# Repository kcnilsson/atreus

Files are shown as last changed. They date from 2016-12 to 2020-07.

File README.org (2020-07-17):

* Atreus Keyboard

This repository is [[https://gitlab.com/technomancy/atreus][moved to GitLab]].

The Atreus is a mechanical keyboard designed primarily to match the
shape of human hands and to be as portable as possible. The case
measures 26x12cm and lacks even a number row, relying heavily upon the
=fn= key. There is a circuit board for this design, but it's also
possible to [[http://wiki.geekhack.org/index.php?title=Hard-Wiring_How-To][manually wire the matrix]].

I've seen a number of existing DIY 40% keyboard designs, but most of
them stagger the rows, which I find very annoying now that I've gotten
used to the columnar layout of the [[https://geekhack.org/index.php?topic=22780.0][Ergodox]]. In addition, many of the
designs I've seen waste a lot of room on the space bar, failing to
take into account the fact that the thumb is the strongest and most
versatile of the fingers. This design avoids both these problems while
taking a more couch-friendly single-piece approach.



See [[./changelog.md][the changelog]] for the various revisions made to the design since
its initial release.

** Kits

You can buy [[http://atreus.technomancy.us][Atreus kits]] that have all the parts you need along with
detailed assembly instructions from http://atreus.technomancy.us. If
you'd rather round up all the parts yourself, that's possible too
since the design is completely open source; see the bill of materials
below.

** Layout

Only a handful of punctuation marks (and no digits) are available
unshifted, and all the modifiers are on the bottom row:

 :    q     w     e     r     t       ||       y     u     i     o    p
 :    a     s     d     f     g       ||       h     j     k     l    ;
 :    z     x     c     v     b       ||       n     m     ,     .    /
 :   esc   tab  super shift bksp ctrl || alt space  fn     -     '  enter

The numbers and most of the punctuation are on the fn layer with a
numpad-style arrangement under the right hand:

 :    !    @     up     {    }        ||     pgup    7     8     9    *
 :    #  left   down  right  $        ||     pgdn    4     5     6    +
 :    [    ]      (     )    &        ||       `     1     2     3    \
 :   L2  insert super shift bksp ctrl || alt space   fn    .     0    =

The =L2= key switches it to the function layer, and tapping =L0= here
brings it back to the first layer.

 :  insert home    ↑    end  pgup     ||       ↑     F7    F8    F9   F10
 :    del   ←      ↓     →   pgdn     ||       ↓     F4    F5    F6   F11
 :                           reset    ||             F1    F2    F3   F12
 :              super shift bksp ctrl || alt space   L0             

The [[https://atreus.technomancy.us/download][firmware]] includes a number of other options, including
colemak and dvorak. [[https://atreus.technomancy.us/qmk][Customizing your layout]] is easy to do with the QMK configurator interface.

** Parts

*** Switches

This layout has five modifiers and 37 non-modifiers.

I strongly prefer the feel and sound of tactile [[https://deskthority.net/wiki/Matias_switch#Click][Matias Clicky]]
switches for typing. However, I like having [[https://deskthority.net/wiki/Matias_switch#Linear][Matias Linear
switches]] switches on the modifier keys (ctrl, alt, super, shift, and
fn) because the tactile effect has no benefit for keys that are held
down, and giving a different response helps you learn the layout more
quickly.

For users that need to operate in sound-sensitive environments like
open offices or libraries,
[[http://deskthority.net/wiki/Matias_switch#Quiet_click][Matias Quiet
Click]] switches are a popular choice since they still offer tactility
without the noise. Other users prefer switches in the
[[http://deskthority.net/wiki/Cherry_MX][Cherry MX]] family, which use
different keycaps and switch plates but still work fine.

*** Diodes

In order to avoid ghosting, each switch needs a diode. The [[https://www.radioshack.com/product/index.jsp?productId=2062587][1N4148]] is a
readily-available choice, but nearly any signal diode would work.

*** Microcontroller

The circuit board design uses a [[http://www.pololu.com/product/3101][Pololu A-star micro]]. Hand-wired boards
can also use a [[http://arduino.cc/en/Main/ArduinoBoardMicro][Arduino Pro Micro]].

Be sure to get a microcontroller without headers so it will fit in
between the bottom layer and the plate. USB micro is preferred over
USB mini for this reason as well.

*** Keycaps

Caps for Matias switches are included in the official kits. Sculpted
caps are also available [[http://matias.ca/order/#keycaps][from Matias]] or by harvesting from old Alps
keyboards. It's recommended that you use unlabeled keys, because due
to the different sizes and orientations of certain keys (backspace,
shift, enter, etc) many of the labels will be incorrect if present.

Cherry switches have more options. This
[[http://pimpmykeyboard.com/dsa-pbt-abs-blank-keycap-sets/][DSA-shaped base set]] (spherical indentations on the key, same profile for each
row) from Signature Plastics has 52 1x keys plus a few extras we won't
use. There are two "deep dish" keys in that set which you can place
under your index fingers on the home row to help guide your hands to
the right spot without looking. However, you only get a single 1.5x
keycap, and the middle two thumb keys both use them, so you might want
to pick up an extra.

** Circuit Board

The =atreus.rkt= program calculates switch and diode positions based
on row/column counts, spacing, and rotation factors, and emits a
=atreus.kicad_pcb= file. The board outline and traces are done by hand
and are stored in the =header.rktd= and =traces.rktd= files
respectively. The =atreus.kicad_pcb= file can be imported into [[http://kicad-pcb.org][Kicad]]
which can export Gerber files suitable for fabrication. A copy of the
Kicad PCB file is included in the repository if you don't want to
recompile it using Racket. Recompiling is only required if you want to
make changes to the procedurally-generated portions of the board.

Unfortunately most PCB fabricators require a minimum order of 10 or
so, making this impractical for one-offs. The PCB is not required, so
for one-off boards it's usually more sensible to stick with a [[http://atreus.technomancy.us/assembly-hand-wired.pdf][hand-wired build]] instead.

** Case

Layered laser-cut wood or acrylic. The [[http://geekhack.org/index.php?topic%3D54759.msg1304117#msg1304117][mark II case]] (EPS files in the
=case/= directory) features 8 screw holes and a kind of "stair step"
design around the top and bottom of the key clusters; mark I has
straight lines.

The files =alps-top-plate-3mm.eps=, =alps-switch-plate-3mm.eps=, and
=bottom-plate-3mm.eps= are to be cut in 3mm acrylic or wood. The
=spacer.eps= file can be cut on something thicker; between 4.5mm and
6mm is recommended. Alternatively you can cut it in 3mm twice. The
spacer needs to be at least as thick as the connector of the USB cable
you're using. If you are using Cherry switches, you should use
=cherry-3mm.eps= for the top, switch, and bottom plates instead, but
the spacer is the same.

There is also a programmatically-implemented version of the case
written in OpenSCAD; it is more flexible (you can tweak the number of
rows/cols, etc and recompile) but it doesn't match the canonical case
exactly; in particular the screw holes are placed differently.

The original case (=case-mk-i.svg=) design is also included; it is
slightly less wide and has a minor asymmetry with the screws on the
bottom side.

On a 100W Epilog laser, the 3mm layers cut in about a minute and a
half. I did a run with 6mm acrylic of the other layers which took
nearly 6 minutes.

Wood cases should be finished with sandpaper and lacquer, shellac, or polyurethane.

** Firmware

The [[https://qmk.fm][QMK firmware]] is
recommended. [[https://atreus.technomancy.us/download][Standard
layouts]] are available precompiled, or you can
[[https://atreus.technomancy.us/qmk][design your own]] in the
configurator.

There is also the older
[[https://github.com/technomancy/atreus-firmware][atreus-firmware]]
custom codebase which works but has fewer features. It is recommended
mostly for learning purposes since the code is much simpler and easier
to understand than QMK. Previously TMK was the recommended choice for
firmware, but QMK has much better documentation and ease of use and is
now recommended.

** Bill of Materials

If you don't want to get [[https://atreus.technomancy.us][the kit]] you can source parts yourself. (You
can also order a partial kit if you want to customize some of the
parts.) Using Cherry switches is cheapest unless you can find cheap
Alps-mount keycaps:

- 50 Matias or Cherry switches from mechanicalkeyboards.com
- 50 diodes from radio shack, ebay, or whatever
- 40 1x, 2 1.5x Keycaps from signatureplastics.com OR full keycap set from matias.ca
- A-star micro from pololu.com
- Case materials from various sources
- Case laser cutting: 7.5 minutes on a 100W Epilog laser; varies by source
- USB micro cable, get anywhere

Recommended but optional:

- 5 linear Matias or Cherry switches

The base keycap set from Signature Plastics only has one 1.5x key,
which is used for the inner thumb keys. You can use a 1x key for one
of them, but it looks kind of tacky, so I recommend getting a second
1.5x keycap separately.

*** Other Tools

You'll need a soldering iron, solder, and a wire cutter. A multimeter
can come in handy for testing the connections but is optional. You'll
also need eight M3 machine screws with nuts; the length of the screws
depends on the thickness of the acrylic you use. You can add rubber
feet to the bottom to prevent the board from sliding around when
placed on a desk. You'll also need sandpaper and lacquer for the
wooden case.

If you are building a hand-wired board you will also need a glue gun,
hookup wire, and wire strippers.

** Assembly

See the [[https://atreus.technomancy.us/assembly.pdf][assembly instructions]] PDF.

Hand-wired boards will want the [[https://atreus.technomancy.us/assembly-hand-wired.pdf][previous edition of the assembly instructions]].

The LaTeX source to the assembly instructions is in the =assembly= directory.

** Inspiration

These fine projects all provided inspiration for various aspects of
the Atreus, as well as the folks on the =#geekhack= freenode channel.

- [[https://geekhack.org/index.php?topic=22780.0][Ergodox]]
- [[http://deskthority.net/workshop-f7/onehand-20-keyboard-t6617.html][OneHand]]
- [[http://blog.fsck.com/2013/12/better-and-better-keyboards.html][keyboard.io]]
- [[http://geekhack.org/index.php?topic=48718][ErgoT]]

** Builds

If you've built an Atreus, please add your name to [[https://github.com/technomancy/atreus/wiki/BuildLogs][the build logs wiki]].

There's also a [[https://atreus.technomancy.us/list][mailing list]] for people who have built or ordered an
Atreus or are interested in doing so.

** Orestes

An [[https://www.flickr.com/photos/technomancy/14654421878][experimental build]] uses the [[http://pjrc.com/store/teensy31.html][Teensy 3]] microcontroller and
ARM [[https://github.com/technomancy/orestes/tree/teensy3][Forth-based]] firmware, but this is not really suitable for general-purpose use; it's more of a curiosity.

** License

Copyright © 2014-2018 Phil Hagelberg and contributors

Released under the [[https://www.gnu.org/licenses/gpl.html][GNU GPL version 3]]

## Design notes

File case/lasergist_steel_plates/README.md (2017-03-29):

Stainless Steel plates using Lasergist
======================================

The Atreus is a great portable ergonomic keyboard. For those who prefer a metal case, the following instructions show you how to build a floating-keys stainless steel Atreus using a switch plate and a bottom plate.

Photos: http://imgur.com/gallery/ZaZHV

Stainless Steel Atreus

The illustrator files are ready to be submitted as-is to Lasergist to make stainless steel plates (Cherry MX version)

Choose the following settings:
* Material: **AISI 304 - Shiny**
* Thickness: **1.5 mm**
* **Sandblasting**

Upload the two files:
* **switch-plate-only.ai**
  * Overall dimensions: height: 116mm width: 257mm
  * Path lengths: 3369mm
* **base-plate-only.ai**
  * Overall dimensions: height: 116mm width: 257mm
  * Path lengths: 749mm

The order comes out to about $95 USD, including shipping.
  
Additionally, you'll need the following hardware:
* 8x 14mm long M3 screws, low profile head https://www.mcmaster.com/#93070A071
* 8x 8mm long M3 hex nuts https://www.mcmaster.com/#94868A603
* 8x M3 small hex nuts https://www.mcmaster.com/#98676A100

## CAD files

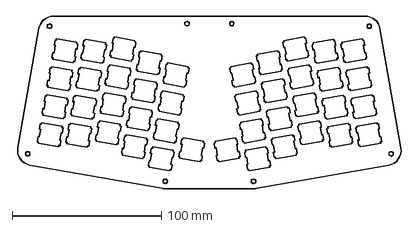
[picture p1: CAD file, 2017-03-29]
case/lasergist_steel_plates/switch-plate-only.dxf
258.3 x 115.8 mm

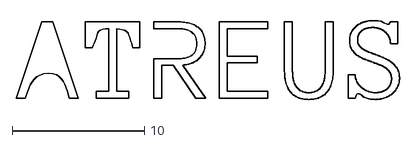
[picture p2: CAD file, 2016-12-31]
case/openscad/logo.dxf
28.9 x 5.96

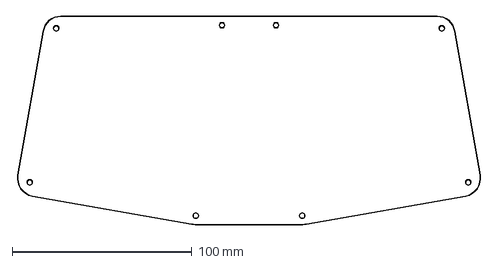
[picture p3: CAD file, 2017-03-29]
case/lasergist_steel_plates/base-plate-only.dxf
258.8 x 115.8 mm

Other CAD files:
case/openscad/atreus_case.scad

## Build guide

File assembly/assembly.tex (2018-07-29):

\documentclass[landscape,twocolumn]{article}
\title{Atreus Keyboard Assembly}
\date{ }
\usepackage{pdflscape}
\usepackage{graphicx}
\usepackage[landscape,twocolumn]{geometry}
\usepackage{wrapfig}
\newgeometry{margin=2cm}
\begin{document}
\setlength{\columnsep}{1.4cm}
\setlength{\parindent}{0cm}
\maketitle
\section{Prerequisites}

Before starting, make sure your kit has all its parts:

\begin{itemize}
\item Case: top plate, switch plate, spacer pieces, bottom plate
\item Sandpaper: 100-220 grit and 1000-2000 grit waterproof
\item Key switches: 42 tactile or clicky, 5 red optional
\item Printed circuit board (PCB)
\item A-Star Micro controller\footnote{The controller and diodes will be
  attached to the PCB already in presoldered boards.}
\item Diodes\textsuperscript{1}: 42
\item USB micro cable
\item Key caps: 40 normal, 2 long
\item Screws and nuts: 8 each, 16mm M3 size
\item Rubber feet
\end{itemize}

You'll also need to have these on hand:

\begin{itemize}
\item Can of spray lacquer, shellac, or polyurethane (for wood cases)
\item Newspaper or other material to spray on (for wood cases)
\item Soldering iron and solder (lead-free not recommended)
\item Wire cutters (not needed for presoldered kits)
\item Eye protection for soldering
\end{itemize}

\vspace{1em}

The latest version of this document can always be found
online.\footnote{https://atreus.technomancy.us/assembly.pdf} If you are
hand-wiring a board without a PCB, see the older assembly
guide.\footnote{https://atreus.technomancy.us/assembly-hand-wired.pdf}
The photos in this guide depict Matias switches (with rectangular
switch stems), but you can use Cherry MX switches (with stems shaped
like a +) as well.

\section{Sanding}

Acrylic cases can skip down to the ``Diodes'' step below. Otherwise
start by sanding with your rougher sandpaper. The top side of the top
plate and the bottom side of the bottom plate are the only surfaces
that are exposed to the touch once the keyboard is fully assembled, so
these are the ones you'll need to sand.

\vspace{1em}
\begin{center}
  
\end{center}
\vspace{1em}

You may want to hold two pieces together while sanding for strength or
placing it on a flat surface you don't mind scruffing up; too much
pressure on a single plate could damage it. Be sure to get all the
wood dust off the pieces before you go on. A clean tack cloth or other
fine cloth works well.

\vspace{1em}

Some people don't like the look of the exposed edges charred black
from the laser cutter. You can choose to sand off the charring, or
alternately cover it all with black ink from a sharpie marker for a
more consistent look, or just leave it alone.

\section{Wood Finishing}

Once the case is sanded down all over with coarse sandpaper, find a
good place to spray the lacquer or polyurethane; either outdoors or in
a well-ventilated garage. Lay down the newspaper with the pieces of
the case on top of it. Spray your first coat of lacquer to the face-up
side of each piece. As you spray to and fro, overlapping the path of
the spray slightly will minimize running. The evenness of the spray
matters less on the internal surfaces of the case, so that's a good
place to practice and get the hang of it.

\vspace{1em}

Check the lacquer directions to see how long your particular product
needs to dry; this can vary from half an hour to many hours. Once your
first coat is dry, flip each piece over and spray the other
side. Repeat for a second coat. After the second coat, you can ignore
all surfaces except for the top of the top plate and the bottom of the
bottom plate since only these are exposed to the outside. At this
point you can take in the switch plate and continue the rest of the
keyboard construction in between applying the further coats.

\vspace{1em}

The outer surfaces should have between five to eight coats applied
total. As you get to the later coats, the end result will be smoother
if you can keep them thinner. After your second-to-last coat dries,
take your fine sandpaper and soak it in water, then sand over the top
and bottom surfaces lightly. Add a final coat and buff it with a fine
cloth. If you make any mistakes or are unhappy with the smoothness of
the finish, let it dry and add another layer until you are satisfied.

\section{Diodes}

If you've got a presoldered board, you can skip ahead to the
``Switches'' section.

\vspace {1em}

If you've never soldered before, there are plenty of good
introductions online.\footnote{This one from Adafruit is great:
  https://learn.adafruit.com/adafruit-guide-excellent-soldering/tools}
Coat the tip of the hot iron thinly with some solder before you
start. The key is to use the iron to heat both the hole and the lead
sticking through it for a second or two, then bring in a dab of the
solder. The solder should melt immediately if the joint is hot enough.

\vspace{1em}

Take five diodes at a time and bend them into a U shape. Place them
into the diode holes next to each switch slot on the unlabeled side of
the board. Each diode has a black band on it; the band should be
pointing in the direction of the arrow on the printed side of
the board. Once all five are in, pinch the legs of the diodes together
to keep them from falling out, then flip the board over and solder
them in place. Make sure they don't protrude up more than necessary.

\vspace{1em}

\vspace{1em}

Once each set of diodes is soldered, trim the diode legs with wire
cutters. Pinch the diode leg as you trim it to keep it from flying
across the room or into an eye. \textbf{Keep the diode legs}; they will be
needed in the next step. Repeat until each diode position is
filled. Note that each row on the bottom needs six diodes instead of five.

\section{Controller}

Once the diodes are in place, you can begin attaching the controller.
If the controller came in a pink bag with its own header pins, you may
be tempted to use them to connect the controller to the circuit
board. Don't do this--they are too big and will prevent the case from
closing when you're done. We will be using the diode legs we just
trimmed instead.

\vspace{1em}

First take the PCB with the labeled side down and fill the four corner
holes in the center ``A-STAR'' section with solder. Insert diode legs
into these holes while melting the solder. Then repeat the process for
the other holes on the left, keeping them pointing as straight as
possible. Leave the rest of the right side alone for now.

\vspace{1em}
\begin{center}\end{center}
\vspace{1em}

Fit the controller over the legs you've attached so far. You can trim
the legs some if it helps get the controller on, but don't cut them to
less than a quarter of the original length. Solder the four corner
pins already connected to the PCB into the corners of the
controller. (The bottom left corner pin of the controller is unused;
the pin above it is used instead.) Try to ensure the controller is as
close to the PCB as possible and not at an angle. Then solder the
other left-side diode legs into the controller as well. Trim them all
with your wire cutters when they are secure.

\vspace{1em}

Eight right-side holes remain. For these, bend four diode legs at a
time into an L shape, and insert them into four of the remaining
holes. Flip the board over and solder the protruding diode legs to the
PCB, then trim them down and flip the board back over. Straighten the
diode legs, then solder and trim them. Repeat for the remaining
right-side holes. From the PCB side, all the holes will be used, but
from the controller side, there will be some unused.

\vspace{1em}
\begin{center}
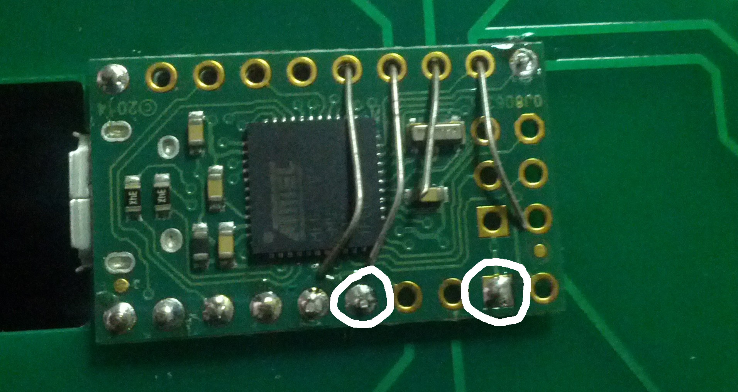
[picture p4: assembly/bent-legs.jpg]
  
\end{center}
\vspace{1em}

Before you go on, take the time to double-check the solder joints on
the controller. The solder should fill the hole completely without
spilling over to adjacent holes. Also check that all the diodes are
facing the correct direction with the black band pointing to the
bottom of the board.

\section{Firmware}

Installing the firmware now isn't strictly necessary, but it will
allow you to spot mistakes before the board is finished.

\vspace{1em}

Plug in the USB micro cable into the controller, and plug the other
side into your computer. Get a copy of the
firmware \texttt{.hex} file \footnote{Available at
  https://atreus.technomancy.us/download} and \texttt{avrdude}. The
first time you upload the firmware, you will have to use the hardware
reset to enter the bootloader: take a diode leg or wire and touch one
end to the reset pin and one end to the ground pin. (These are circled
in the photo.)  Touch them together twice in under a second and the
LED underneath will begin pulsing in a smoother pattern from the
original blinking. This indicates it has entered bootloader mode for 8
seconds.

\vspace{1em}

While it's in the bootloader mode, run \texttt{avrdude -p atmega32u4
  -c avr109 -U flash:w:atreus.hex -P /path/to/usb} from the directory
containing the firmware\footnote{See
  https://atreus.technomancy.us/flash for how to determine the USB
  argument and customizing the layout.}. The firmware should be
uploaded, and it will start functioning as a keyboard once switches
are connected. Next time you upload, you can use the reset key instead
of touching the pins together.

\section{Switches}

Next take four switches and place each switch in a corner of the
switch plate. (That's the case layer with all the holes in it.) The
switches should be oriented so that the side with pins is to the
``north'' of the board so they will fit into the holes in the circuit
board. Put the switch plate face-down on the table with the pins
sticking up.

\vspace{1em}

Carefully fit the circuit board over the protruding pins with the
labeled side down. Solder those corners to hold the circuit board and
the switch plate together. The switches should be flush with the
PCB. Take care that the switch pins are straight when you insert them;
pushing in a switch with a pin that's a bit bent will bend it flat and
prevent it from poking through the circuit board.

\vspace{1em}
\begin{center}
  
\end{center}
\vspace{1em}

Next fill in the rest of the bottom row (SW1:3 through SW10:3) and the
leftmost column (SW0:1 and SW0:2). If your kit has red linear switches
which do not have any tactile bump, you can choose to use these for
the modifier keys (shift, ctrl, alt, etc) or to leave the modifiers
using the same switches as the rest of the board.\footnote{Since
  modifier keys are held down, they do not benefit from tactility like
  normal keys do, so some people find they prefer linear keys there,
  but this is a matter of personal taste.} The modifiers on the bottom
row are SW2:3, SW3:3, and SW8:3 in the default layout.

\vspace{1em}

Solder the left and right pins of each of the switches you've placed
so far, and then plug it in to a computer to test them to ensure that
each row and column is connected back up to the controller
correctly. Once you've confirmed this, solder the rest of the
switches.

\section{Wrapping Up}

If there's a misbehaving switch, it's often caused by a cold
joint. Reflow the solder on both contacts of the switch and the
diode. If an entire row or column is affected, it's probably the
connection to the controller. You can follow the traces for the rows
back to the middle, but the columns on the back of the board are
obscured when the keyboard is assembled; you can see them in this PCB
diagram\footnote{https://atreus.technomancy.us/pcb}. Re-melting the
controller's solder joint for the affected row or column is usually
enough to get it working. If you still can't
get it working, email me: \texttt{phil@hagelb.org}.

\vspace{1em}

You may want to add strain relief by wrapping the USB cable with
electrical tape at the point just below where it leaves the case. This
will make it so pulling on the cable does not dislodge it from the
controller.

\vspace{1em}

After the switches are all in and tested, place the keycaps. They can
take a fair bit of pressure to go on, so support the underside of the
board while pushing them on. Once the caps are on, they are very
difficult to remove again; don't try to pull them off without
desoldering\footnote{Desoldering a single switch can be done with just
  an iron, but for doing more you may want a pump or wick. See
  https://blog.adafruit.com/2015/11/25/collins-lab-desoldering/} the
switch first.

\vspace{1em}

All that's left is to do is close the case by placing the spacer
pieces and bottom plate on the keyboard while upside down, then
putting some screws in. Flip it over and place the top plate on, then
attach the nuts. If the controller was not attached close enough to
the circuit board, it may be necessary to sand down the USB connector
to reduce its height in order to close the case. If the rubber feet
don't stay on with the provided adhesive, white glue may be needed to
secure them. If you have some wood finishing oil or beeswax, you can
apply it with your fingers after the feet go on for a shinier surface.

\vspace{1em}

Congratulations! Enjoy your new keyboard. It will take a
considerable adjustment period to get used to it, but it should result
in much more comfortable and effective typing. Also remember that
you're encouraged to customize the layout to make it truly your
own. Happy typing!

\end{document}

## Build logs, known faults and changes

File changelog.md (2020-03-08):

# Change log

This is a listing of all changes and prototypes for the Atreus
keyboard design. Changes to the
[Atreus Deck](https://atreus.technomancy.us/marki) are elsewhere.

## Keyboardio Atreus: 2020-03-17

* Completely redesigned factory-produced case.
* Metal switch plate.
* USB C port.
* Optionally labeled XDA keycaps.
* 15mm smaller in two dimensions.

## NX-04: 2019-05-25

This was the first prototype to incorporate the redesigned PCB by
Jesse Vincent.

* 2 additional keys.
* wooden case with 4 layers instead of 5.
* detachable USB cable.
* swappable Cherry MX switches.
* surface-mount controller and diodes.
* Kaleidoscope is the default firmware.

## Mark 3.8: 2018-7-28

* QMK is the default firmware for all boards now.

## Mark 3.7: 2017-6-29

* Manually bending middle switch pins on Alps is no longer necessary.
* Spacer layer is split into three pieces to be less wasteful with materials.

## Mark 3.6: 2016-3-14

* TMK is the default firmware.
* New layout with arrows on the fn layer.
* PCB is now label-side up by default.

## Mark 3.5: 2015-6-23

* Change to Matias switches.

## NX-03: 2015-05-08

* Matias Clicky switches.
* Alps-compatible switch plate.

## Mark 3.1: 2014-11-25

* [Second revision of circuit board](http://gerblook.org/pcb/jweM8BcTbgKCL4zsj8tEYj).
* Arrows on L2 shifted over one column.
* Circuit board license changed to match the rest of the Atreus project.

The second revision of the circuit board exposes the reset pin,
removing the need for hookup wire described below. It also removes
[the need to cut a notch in the circuit board](https://www.flickr.com/photos/technomancy/15862732742)
to allow the USB connector more clearance.

The layout changed slightly by shifting the arrow keys on L2 over one
column so they can be hit from the normal position without the pinky key.

## Mark 3: 2014-10-30

* Initial [board design](http://gerblook.org/pcb/zqMY66AEsKz3xehSrdoDV6) in KiCAD + Racket.
* Assembly guide updated to include wood finishing.
* Cable hole in case spacer has rounded edges.
* New layout: multidvorak.
* Switch to Pololu A-Star Micro controller. (also USB mini->micro)

A
[circuit board was designed in KiCAD with the switch placement logic written in Racket](http://technomancy.us/176). The
first revision of the circuit board does not expose the reset pin, so
hookup wire is needed to provide a backup reset mechanism once the board
is fully assembled. The firmware contains a reset mechanism, but if
bugs in the firmware prevent it from being activated, the back case
can be removed and the hookup wires can be connected twice in a second
to initiate a reset.

The new design replaced the Teensy 2 microcontroller with the smaller
[A-Star Micro](http://www.pololu.com/product/3101) which uses a USB
Micro connector instead of USB Mini.

The new multidvorak layout allows the firmware to support hardware
dvorak and software dvorak simultaneously. The edges of the cable hole
are rounded off to reduce strain on the cable.

## NX-02: 2014-08-05

* Matias Quiet Click switches.
* Teensy 3: ARM-based microcontroller.
* Orestes: firmware written in Forth.

An
[experimental prototype](https://www.flickr.com/photos/technomancy/14654421878)
using Matias Quiet Click switches and the ARM-based Teensy 3
controller. The Matias switch shape was supported by cutting the
notches out of each switch hole individually with a knife.

Porting the firmware to the ARM platform was accompanied by porting
[an implementation of Forth](https://github.com/technomancy/orestes/tree/teensy3)
and porting the firmware logic to that.

## Mark 2: 2014-04-22

* New OpenSCAD [case design](https://www.flickr.com/photos/technomancy/14719013574) by Constantine.
* New layouts: hardware dvorak, hardware colemak.
* Assembly guide.

The case was
[redesigned in OpenSCAD](https://github.com/technomancy/atreus/blob/master/case/openscad/atreus_case.scad)
to be easier to produce from mail-order laser cutting services. This
revision can be recognized by its use of eight screws instead of the
original seven. The cuts in the top plate around the switches are also
much closer to the switches themselves.
[A second independent build](http://geekhack.org/index.php?topic=57007.msg1292144)
was documented.

The assembly process is documented properly.

## Mark 1: 2014-04-01

* Custom Atreus firmware in C.
* Layout changes; new layer.

A
[custom Atreus-specific firmware codebase](https://github.com/technomancy/atreus-firmware)
was started. Digits were moved to a numpad arrangement and the L2
layer (function and arrow keys) was added. The first
[third-party build](http://blog.tarn-vedra.de/2014/04/reproducing-keyboard-science_1707.html)
was documented.

## NX-01: 2014-02-22

* [Initial prototype](https://www.flickr.com/photos/technomancy/12805226463)!
* Case hand-drawn in Inkscape.
* Teensy 2 microcontroller, hand-wired matrix.
* Uses TMK firmware.

This was the first Atreus,
[created solely for personal use](http://technomancy.us/173) and
meticulously hand-wired with a number of errors. Support for the
Atreus was
[added to the TMK firmware codebase](https://github.com/technomancy/tmk_keyboard/tree/atreus),
but power-saving bugs in TMK meant that it occasionally dropped key
presses on low-voltage laptops.

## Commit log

2016-12-31 WIP: bringing openscad version in line with canonical one.
    This change shifts the shape of the case a bit to match the EPS one,
    but it also goes back to a 7-screw design instead of 8-screw.
    It also attempts to reintroduce the logo, but due to an openscad bug
    the logo is incomplete.
    Stop using deprecated child() function.
    [atreus_case.scad, logo.dxf]
2017-02-02 Fixed matias link in BOM
2017-02-27 added illustrator files and readme
    [base-plate-only.dxf, switch-plate-only.dxf]
2017-03-27 added specs for the screws and nuts
2017-03-28 renamed directory
    [base-plate-only.dxf, switch-plate-only.dxf]
2017-04-11 Updated assembly instructions
2017-04-15 Landscape assembly guide, with some revisions.
2017-08-02 Add VCarve file for the keyboard case
2017-08-07 Split spacer for the case.
2017-08-07 Make the case files clearer for Alps vs Cherry.
2017-08-07 Bending middle pins for Matias switches is no longer necessary.
2017-10-21 Replace child() with children().
    [atreus_case.scad]
2018-06-02 Minor assembly instruction improvements.
2018-07-28 Some assembly updates.
2019-03-27 Redesign PCB; rev 3.
    [atreus.kicad_pcb]
2019-03-29 Programmatically place repeated traces.
    [atreus.kicad_pcb]
2019-03-31 Revert changes to create split PCB.
    [atreus.kicad_pcb]
2019-03-31 Add two middle switches, raise microcontroller pads.
2019-04-09 Case design in Racket.
2019-08-24 First pass at 4th deck prototype.
2021-05-11 Fixed Edge.cuts layout so that the bottom switches are not cut in half
    [atreus.kicad_pcb]
2021-05-13 Updated edge.cuts for larger board
